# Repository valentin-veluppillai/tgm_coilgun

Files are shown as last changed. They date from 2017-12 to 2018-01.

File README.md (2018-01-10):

# tgm_coilgun
Coilgun (or magnetic accelerator) built at tgm, for educational purposes
## software used
* processing - used for coding the UI
* kiCad - schematic and layout design
* avrstudio - programming of the microcontroller
## user interface
Written in Java/processing using the controlp5 library. The computer running
the UI communicates with the mincontroller via USART. The UI allows the user to
specify the timing of the coil power supplies.

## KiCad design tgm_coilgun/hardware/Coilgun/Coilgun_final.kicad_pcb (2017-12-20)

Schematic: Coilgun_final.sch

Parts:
C1, C2: 16pF; CP_Radial_D5.0mm_P2.50mm
C3: xF; CP_Radial_D5.0mm_P2.50mm
F1: FTDI
J1, J3, J4, J5, J6, J7: ST; ScrewTerminal
J2: ISP_HEADER
M1, M2, M3: L6115; Multiwatt-15
R1: 1k; R_Axial_DIN0207_L6.3mm_D2.5mm_P10.16mm_Horizontal
S1: LightSensor
U1: ATMEGA8535-16PU; DIP-40_0_ELL
Y1: 16MHz; QuarzCrystal

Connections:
/COIL_1: J1.1, J1.2, M1.1 (S1), M1.3 (S2), M1.13 (S3), M1.15 (S4)
/COIL_2: J3.1, J3.2, M2.1 (S1), M2.3 (S2), M2.13 (S3), M2.15 (S4)
/COIL_3: J4.1, J4.2, M3.1 (S1), M3.3 (S2), M3.13 (S3), M3.15 (S4)
/MISO: J2.1, U1.7
/MOSFET_EN: M1.6 (EN), M2.6 (EN), M3.6 (EN), R1.1, U1.33
/MOSI: J2.4, U1.6
/RESET: J2.5, U1.9
/SCK: J2.3, U1.8
/VCC_COIL: J5.1, J5.2, M1.2 (D1), M1.4 (D2), M1.12 (D3), M1.14 (D4), M2.2 (D1), M2.4 (D2), M2.12 (D3), M2.14 (D4), M3.2 (D1), M3.4 (D2), M3.12 (D3), M3.14 (D4)
/VCC_MCU: C3.2, J2.2, J6.1, U1.10, U1.30, U1.32
/VCC_MOSFET: J6.2, M1.5 (VCC), M2.5 (VCC), M3.5 (VCC)
GND: C1.2, C2.2, C3.1, F1.9 (GND), F1.16 (GND), J2.6, J7.1, J7.2, M1.8 (GND), M2.8 (GND), M3.8 (GND), R1.2, U1.11, U1.31
unnamed: C1.1, U1.12, Y1.1
unnamed: C2.1, U1.13, Y1.2
unnamed: F1.10 (TXD), U1.14
unnamed: F1.14 (RXD), U1.15
unnamed: M1.7 (IN1), M1.9 (IN2), M1.10 (IN3), M1.11 (IN4), U1.40
unnamed: M2.7 (IN1), M2.9 (IN2), M2.10 (IN3), M2.11 (IN4), U1.39
unnamed: M3.7 (IN1), M3.9 (IN2), M3.10 (IN3), M3.11 (IN4), U1.38
unnamed: S1.1 (DATA1), U1.16
unnamed: S1.2 (DATA2), U1.17

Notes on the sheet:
Higher Voltage and Current Containment This is connected separately
Low Voltage and Current containment Not dangerous

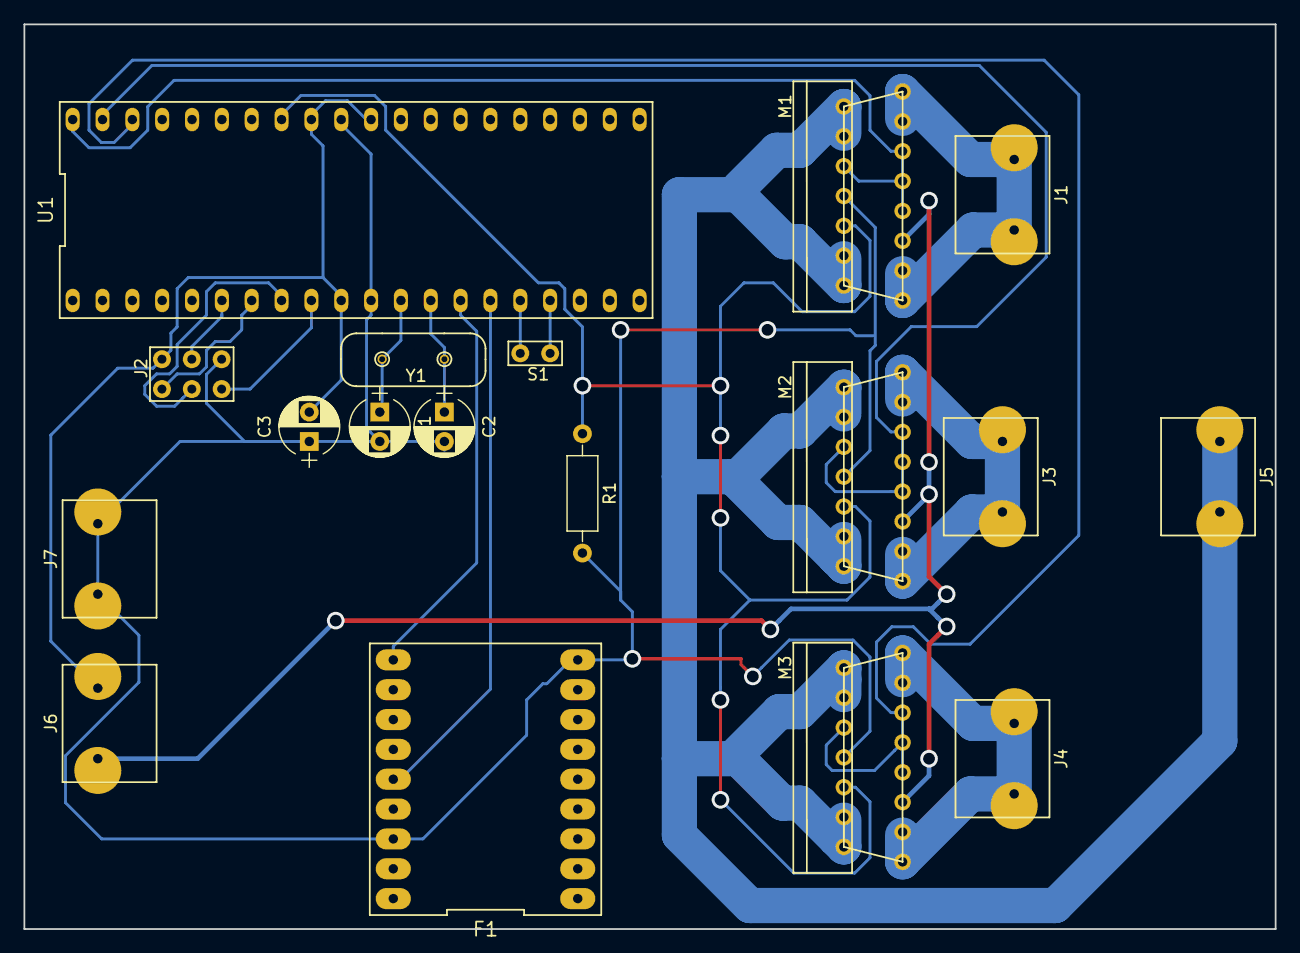
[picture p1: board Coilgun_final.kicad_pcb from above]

Board: 2 copper layers, 106.5 x 77.0 mm, 18 parts (0 on the bottom side), 21 nets.

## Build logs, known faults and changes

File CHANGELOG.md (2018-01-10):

# Changelog
## [0.3] - 10.1.18
### Changed
* uC control code
## [0.2] - 9.1.18
### Added
* uC control code
### Changed
* ui code comments
## [0.1] - 22.12.17
### Added
* new schematic and layout
### Changed
* simplified and updated ui code
### Removed
* old arduino files
* high score sounds

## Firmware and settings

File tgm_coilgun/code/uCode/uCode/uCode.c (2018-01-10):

/*
 * Coil
 *
 * Created: 2017
 * Author : Moser, Veluppillai
 */

/*	Timers:
	-timer_0: 8_bit_timer for coil-counting, prescaler = 1, compare match at 160, ovf_int not enabled
	-timer_1: 16_bit_timer for time-measurements, prescaler = 1, only ovf_int enabled, no compare match

	USART:
	-BAUD_RATE = 9600, UBRR = 103
*/

#define FOSC 16000000	// Clock Speed
#define BAUD 9600
#define MYUBRR FOSC/16/BAUD-1

#include <avr/io.h>
#include <avr/interrupt.h>
#include <avr/eeprom.h>

uint32_t time[3] = {0};		//store timings for coils (moser 2lazy4arrays)

uint32_t ovf_count_t0 = 0; 	//chk size
uint32_t ovf_count_t1 = 0;		//here 2

uint32_t bullet_time = 0;		//var for bullet travel time
uint8_t dun = 0;
//bullet speed interrupts

ISR(INT0_vect) {		//lower light barrier triggered
	TCCR1B = 1;		//start timer
	return;
}

ISR(INT1_vect) {		//upper light barrier triggered
	TCCR1B = 0;		//stop timer 1 and save value
	bullet_time = 4096 * ovf_count_t1 * 1000 + TCNT1 * 625 / 10;	//1 ovf = 4096us, 100 tics = 6.35us => 1 tic = 63.5ns --- that whole shit is in nanoseconds, with a 32 bit integer, unsigned, that should be enough
	dun = 1;
	return;
}

ISR(TIMER1_OVF_vect) {
	ovf_count_t1++;
}

ISR(TIMER0_COMP_vect) {
	if(ovf_count_t0 * 10 <= time[1]) {
		PORTB &= ~(0<<PORTB0);
	}
	if(ovf_count_t0 * 10 <= time[2]) {
		PORTB &= ~(0<<PORTB1);
	}
	if(ovf_count_t0 * 10 <= time[3]) {
		PORTB &= ~(0<<PORTB1);
		TCCR0 &= ~(1<<CS00||1<<CS01||1<<CS02);		//stop timer 0
	}
	ovf_count_t0++;
	return;
}

void USART_Init() {
	UBRRL = 0x67;	//set baud rate
	UCSRC = 0x06;	//configure format
	UCSRB = 0x18;	//enable transmitter and receiver
}

uint16_t eepromVar1 EEMEM;
uint16_t eepromVar2 EEMEM;


int main(void) {
	
	//setup timers
	OCR0 = 160;
	OCR1A = 1600;
	
	//setup USART
	DDRD = 0x00;
	DDRD |= (1<<PD0)|(1<<PD1);
	USART_Init();
	
	while(1) {
	
	//beginn reception of data
	for(int i = 0; i < 3; i++) {
		for(int j = 0; j < 4; j++) {
			while(!(UCSRA & (1<<RXC)));
			time[i] |= (UDR<<(8*j));
		}
	}
	
	//start launch
	//setup coil-pins
	DDRA = 0xFF;
	PORTA = 0x00;
	PORTA |= (1<<PA7);
	
	eeprom_update_word(&eepromVar1, (uint16_t)(time[1]));
	eeprom_update_word(&eepromVar2, (uint16_t)(time[1]>>16));
	
	//activate timer 0
	/*
	sei();
	TCCR0 = 1;
	TIMSK |= (1<<OCIE0);
	
	//enable pin interrupts
	MCUCR |= 0x0F;
	
	//wait till timer 1 was stopped
	while(dun==0);
	cli();
	//transmit the nanosecond time
	for(int i = 0; i < 4; i++) {
		while(!(UCSRA & (1<<UDRE)));
		UDR = (char)(bullet_time>>(8*i));
	}
	bullet_time = 0;*/
	
  }
}

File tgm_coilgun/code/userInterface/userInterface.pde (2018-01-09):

/*
userInterface.pde


author: valentin veluppilai
project: tgm_coilgun
version: 0.1
date: 22.12.17

simple ui for the coilgun. only works when an appropriate device is connected

transmission of data in function controlEvent()
order: coil 1 (bottom), coil 2 (middle), coil 3 (top)
*/

import controlP5.*;
import processing.serial.*;


ControlP5 controlP5;
//Serial.list() can be replaced with path to serial device when used on linux
Serial serial = new Serial(this, Serial.list()[1], 9600);
PImage logo;


int tmpint;
int counter = 2;      //used to calculate the average score
int time1 = 0;        //⬎
int time2 = 0;        // coil times
int time3 = 0;        //⬏

float dist = 0.03;    //distance between two light sensors
float hs = 14.896;    //high score
float as = 12.947;    //average score
float us = 13.768;    //user score
float score;          //seems redundant, go check

byte[] tmp = new byte[4];     //temporary storage of serial transmission
byte[] time1b = new byte[4];  //⬎
byte[] time2b = new byte[4];  //stores scores in bytes, needed for transmission
byte[] time3b = new byte[4];  //⬏

String tmpstring;   //used in the processing of the serial transmission

void setup() {
        controlP5 = new ControlP5(this);
        PFont pfont = createFont("Arial",20,true);
        ControlFont cf1 = new ControlFont(pfont, int(height*0.0555556));
        logo = loadImage("tgmlogo.png");

        controlP5.addSlider(" Coil 3")  //top coil
        .setRange(1,100)
        .setValue(1)
        .setPosition( int(width*0.078125), int(height*0.0740741))
        .setSize( int(width*0.3125),int(height*0.0648148))
        .setFont(cf1);

        controlP5.addSlider(" Coil 2")  //middle coil
        .setRange(1,100)
        .setValue(1)
        .setPosition( int(width*0.078125), int(height*0.1666667))
        .setSize( int(width*0.3125), int(height*0.0648148))
        .setFont(cf1);

        controlP5.addSlider(" Coil 1") //bottom coil
        .setRange(1,100)
        .setValue(1)
        .setPosition( int(width*0.078125), int(height*0.2592593))
        .setSize( int(width*0.3125), int(height*0.0648148))
        .setFont(cf1);

        controlP5.addButton("Engage")
        .setPosition( int(width*.15625), int(height*0.3703704))
        .setSize( int(width*0.15625), int(height*0.1296296))
        .setFont(cf1);

        smooth();string
        fullScreen();

}

void draw() {

  background(0);
  fill(255);

  if(serial.available() > 0) {
    tmp = serial.readBytes();
    //redo this
    tmpstring = new String(tmp);    //convert transmission to srting
    tmpint = Integer.parseInt(trim(tmpstring)); // ---"--- to int
    //sometime
    us = dist/(float(tmpint)/1000000);   //convert measured time to speed
    if(score > hs)
        hs = us;
    counter = counter + 1;
    as = ( (as * (counter -1) + us) / counter);
  }

  textAlign(LEFT);
  textFont(createFont("Arial", int(height*0.0185185),true));
  text("HIGHSCORE", int(width*0.5989583), int(width * 0.0416667));
  text("AVG. SCORE", int(width*0.5989583), int(width * 0.1145833));
  text("YOUR SCORE", int(width*0.5989583), int(width * 0.1875));

  textFont(createFont("Arial", int(height*0.1111111),true));
  text(nf(hs, 0, 2) + " m/s", int(width*0.5989583), int(width * 0.09375));
  text(nf(as, 0, 2) + " m/s", int(width*0.5989583), int(width * 0.1666667));
  text(nf(us, 0, 2) + " m/s", int(width*0.5989583), int(width * 0.2395833));

  imageMode(CENTER);
  image(logo, width/2, 3*height/4, logo.width*2, logo.height*2);

}

//cp5 function, is called everytime the user interacts with an cp5 objects
void controlEvent(ControlEvent theEvent) {
  if(theEvent.isController()) {
    if(theEvent.getController().getName()==" Coil 1") {
      time1 = int(1000 * controlP5.getController(" Coil 1").getValue());
      time1b = adjustByteArray(intToByte(time1));
    }

    if(theEvent.getController().getName()==" Coil 2") {
      time2 = int(1000 * controlP5.getController(" Coil 2").getValue());
      time2b = adjustByteArray(intToByte(time2));
    }

    if(theEvent.getController().getName()==" Coil 3") {
      time3 = int(1000 * controlP5.getController(" Coil 3").getValue());
      time3b = adjustByteArray(intToByte(time3));
    }

    if(theEvent.getController().getName()=="Engage") {
      serial.write(time1b);
      serial.write(time2b);
      serial.write(time3b);
    }
  }
}

public static byte[] intToByte(int value) {  //converts an int to byte[4]
  byte[] byteArray = new byte[4];
  int shift = 0;
  for (int i = 0; i < byteArray.length; i++) {
    shift = i * 8; // go through each bit (0,8,16,24)
    byteArray[i] = (byte) (value >>> shift);
  }
  return byteArray;
}

public byte reverseByte(byte x) {   //reverses a byte
  int intSize = 8;
  byte y=0;
  for(int position=intSize-1; position>=0; position--){
    y+=((x&1)<<position);
    x >>= 1;
  }
  return y;
}

public byte[] adjustByteArray(byte[] x) { //reverses every byte in a byte[]
  for(int i = 0; i < x.length; i++) {
    x[i] = reverseByte(x[i]);
  }
  return x;
}

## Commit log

2017-12-19 Add files via upload
    uploaded pre-github files
    [Coilgun.kicad_pcb, Coilgun.sch]
2017-12-20 Updated Schematic and Layout
    [Coilgun_final.kicad_pcb, Coilgun_final.sch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]
2017-12-22 arduino stuff not needed
